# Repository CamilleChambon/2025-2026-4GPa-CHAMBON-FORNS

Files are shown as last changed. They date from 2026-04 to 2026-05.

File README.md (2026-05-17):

# 2025-2026-4GPa-CHAMBON-FORNS-GIRAUD
## SOMMAIRE
*** 
  - [I. Description Projet Graphite](#description-projet-graphite)
  - [II. Livrables](#livrables)
  - [III. Matériel nécessaire](#matériel-nécessaire)
  - [IV. Electronique Analogique sous LTSpice](#electronique-analogique-sous-ltspice)
  - [V. Création du PCB sous KiCad](#creation-du-pcb-sous-kicad)
  - [VI. Réalisation du shield](#réalisation-du-shield)
  - [VII. Code Arduino](#code-arduino)
  - [VIII. Application Android](#application-android)
  - [IX. Banc de test](#banc-de-test)
  - [X. Datasheet](#datasheet)
  - [XI. Conclusion](#conclusion)

*** 

## Description Projet Graphite

&nbsp;&nbsp;&nbsp;&nbsp;&nbsp;&nbsp; Dans le cadre du cours "Du capteur au banc de test" de 4e année de Génie Physique, nous avons développé un capteur de contrainte basé sur une technologie low-tech. Comme présenté en introduction de la datasheet (cf. section X), le capteur Graphite est un capteur de contrainte résistif, composant passif qui fonctionne en mesurant les variations de résistance d'une fine couche de graphite appliquée au crayon à papier sur une surface papier. Lorsque ce dernier est déformé en tension ou en compression, la répartition des particules de graphite est modifiée, entraînant respectivement une hausse ou une baisse de sa résistance. Par la mesure de ces variations de résistance, il est possible de remonter à la variation de résistance. 

&nbsp;&nbsp;&nbsp;&nbsp;&nbsp;&nbsp; Le projet a consisté à développer un système complet autour de ce capteur : modélisation d'électronique analogique grâce au logiciel LTSpice, création d’un circuit imprimé (PCB) via Kicad, programmation avec Arduino, création d'une application mobile avec MIT App Inventor, et communication sans fil par Bluetooth, entre le téléphone et le système. Un banc de test a été spécialement réalisé en impression 3D pour évaluer les performances du capteur, grâce à des pièces circulaires de différents rayons de courbure. En ce qui concerne les codes, ayant rencontré des problèmes pour faire fonctionner l'écran OLED, nous avons rédigé deux codes distincts, l'un avec l'écran, l'autre sans.

## Livrables

  - Shield PCB compatible avec Arduino UNO, intégrant un capteur graphite, un amplificateur transimpédance, un module Bluetooth, un écran OLED, un flex sensor, un potentiomètre digital et un encodeur rotatoire.
  - Code Arduino assurant la lecture du capteur, l’affichage des données, la communication Bluetooth et l’interaction avec les composants.
  - Application Android réalisée sous MIT App Inventor pour visualiser les mesures transmises par Bluetooth.
  - Graphes des variations relatives de résistance du capteur graphite - en tension et en compression - et du flex sensor pour montrer les résultats obtenus sur le banc de test.
  - Datasheet du capteur de graphite, présentant ses principales caractéristiques, les résultats expérimentaux et un exemple de circuit d'utilisation courant.

## Matériel nécessaire

  - 1 carte Arduino Uno
  - 2 Résistances de 100kΩ
  - 1 Résistance de 1kΩ
  - 1 Potentiomètre digital MCP-41050
  - 2 Condensateurs 100nF
  - 1 Condensateur 1µF
  - 1 Amplificateur LTC1050
  - 1 Écran OLED01
  - 1 Module Bluetooth HC-05
  - 1 Encodeur rotatoire 

## Electronique Analogique sous LTSpice

Notre capteur graphite présente une résistance de l’ordre du gigaOhm, ce qui génère un courant de quelques pico à nano Ampères sous une tension de 5 V. Pour rendre ce signal exploitable par l’ADC d’une Arduino UNO, nous avons conçu un amplificateur transimpédance autour de l’AOP LTC1050. Après avoir modélisé le capteur et le montage sous LTspice pour déterminer la meilleure valeur de la résistance de rétroaction, nous avons ajouté trois étages de filtrage, fondés sur des filtres passe-bas, afin d'améliorer la qualité du signal en éliminant les hautes fréquences parasites, en atténuant le bruit secteur à 50 Hz et en supprimant les interférences liées à l’ADC.  

Ce circuit convertit ainsi le faible courant issu du capteur en une tension propre, directement lisible et traitable par la carte Arduino.

<p align="center">
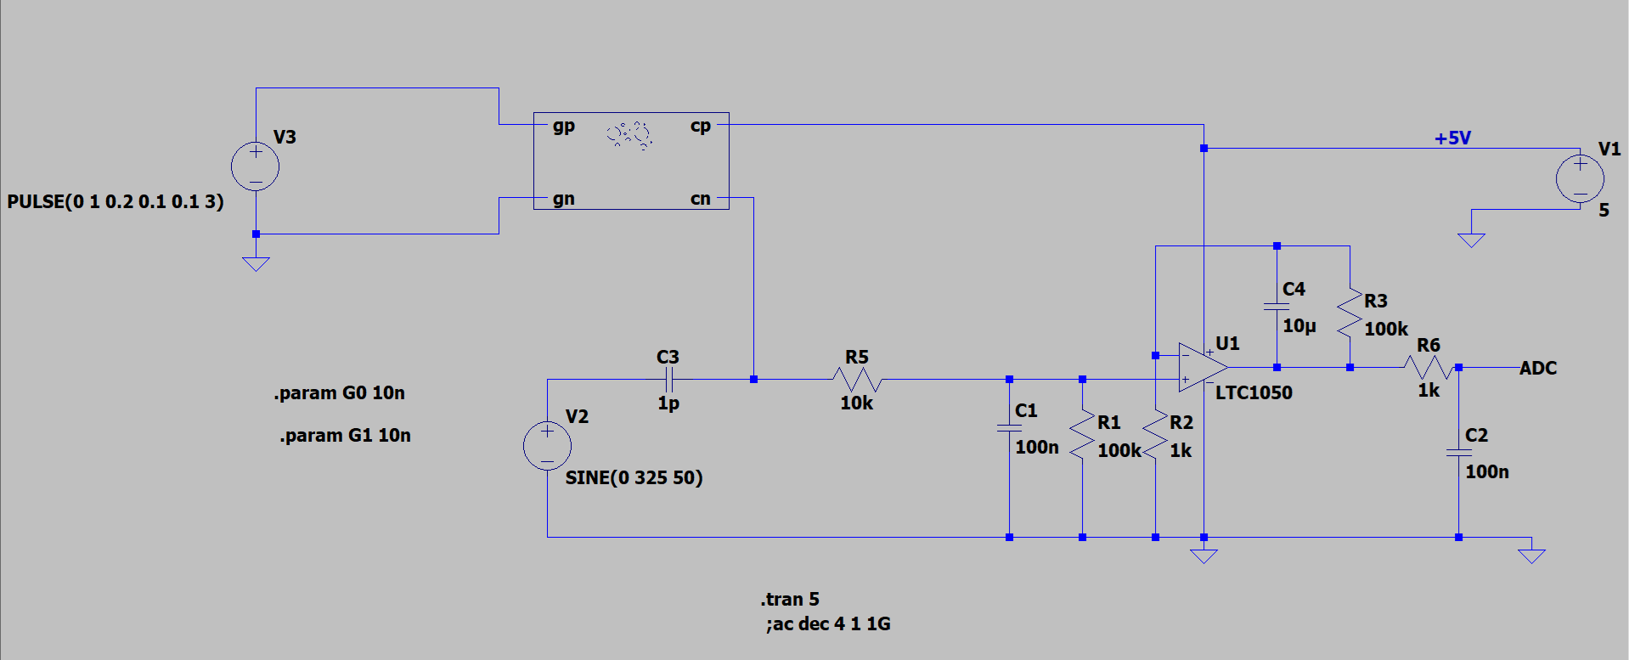
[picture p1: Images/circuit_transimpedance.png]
Figure 1 - Circuit amplificateur

<br>
<i>Circuit amplificateur transimpédance</i>
</p>

## Création du PCB sous KiCad

Lors de la phase de conception du shield, nous avons d’abord repris le gabarit d’une carte Arduino UNO dans KiCad (version 8.0) puis nous avons créé sur le même logiciel les symboles et empreintes manquants pour l'ensemble des composants que nous utiliserions, en respectant leurs dimensions et l’écartement des broches. Voici le schéma électrique de l'ensemble de notre montage :

<p align="center">
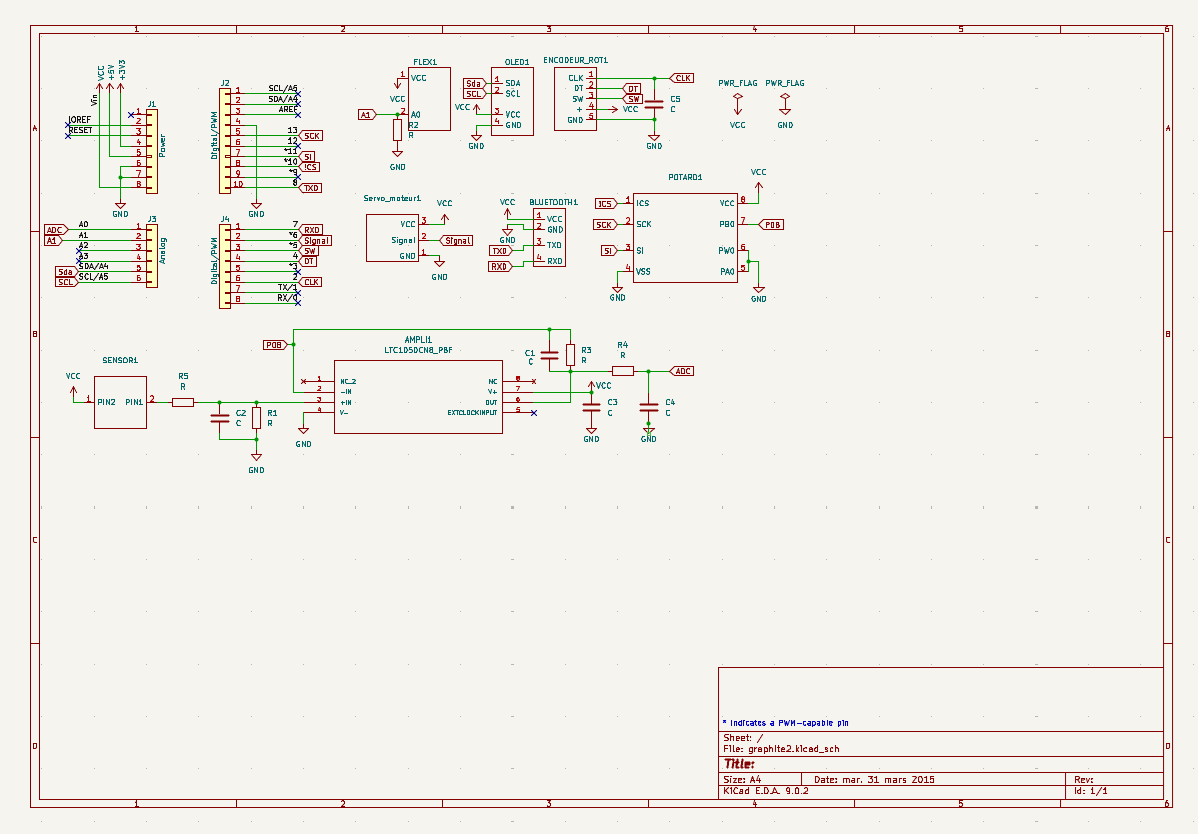
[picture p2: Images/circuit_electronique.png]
Figure 1 - Circuit électronique

<br>
<i>Circuit électronique</i>
</p>

Une fois notre bibliothèque faite, nous avons assemblé le schéma électrique complet : chaque composant est relié selon le fonctionnement prévu. Sur la vue PCB, nous avons disposé les empreintes, effectué le routage des pistes, le tout afin d'optimiser l'espace disponible et de limiter le nombre de vias réalisés. Les résistances ont été positionnées verticalement sur le PCB. Enfin, nous avons ajouté un plan de masse pour relier certaines pistes au GND.
Voici notre PCB :

<p align="center">
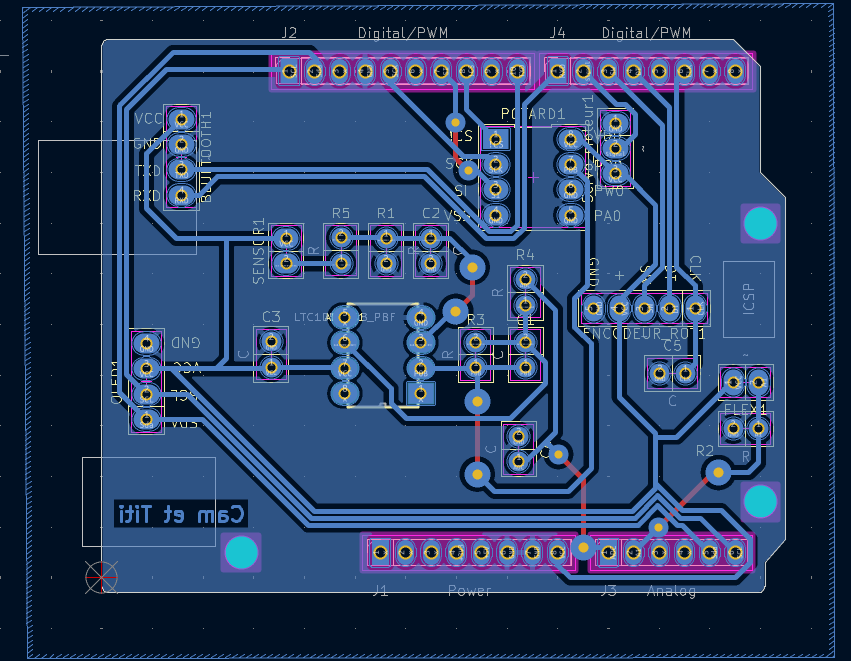
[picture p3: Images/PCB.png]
Figure 1 - PCB Final

<br>
<i>PCB</i>
</p>

Le résultat est un circuit imprimé prêt à être fabriqué et à recevoir chaque composant sur le shield Arduino UNO.

## Réalisation du Shield

Nous avons commencé par l’édition du masque de gravure de notre circuit imprimé (PCB) à l’aide du logiciel KiCad. Ensuite, nous avons procédé à l’insolation UV d’une plaquette recouverte d’une fine couche de cuivre et de résine photosensible. La plaquette a été immergée dans un révélateur chimique, ce qui permet d’éliminer la résine non exposée aux UV. Par la suite, on plonge la plaquette dans du perchlorure de fer pour graver les pistes du circuit en dissolvant le cuivre non protégé. Enfin, il faut un nettoyage à l’acétone pour retirer les résidus de résine restant sur la plaquette. A la fin de ce travail, nous avions notre circuit imprimé avec toutes les pistes tracées.
Une fois le PCB réalisé, nous n'avions plus qu'à le percer et y souder tous nos composants. Voici notre PCB final :

<p align="center">
<img src="Images/shield.jpg"Figure 4 - Notre PCB">
<br>
<i>Notre PCB</i>
</p>

## Code Arduino 

Ce projet a été piloté par un [programme Arduino](Code%20Arduino). Pour utiliser les fonctions spéciales à tous les composants, nous avons installé les librairies Adafruit_SSD1306.h et Adfruit_GFX.h, SPI.h, Servo.h et SoftwareSerial.h.

Nous avons joint sur ce github deux codes distincts, avec des caractéristiques communes cependant.

Le code intitulé "code_final" est un code qui utilise les deux capteurs (flex et graphite), le servo-moteur, le module bluetooth et le potentiomètre. Il réalise deux étapes : une calibration, pour ramener à 2,5 V, la tension lue aux bornes du capteur graphite sans déformation, puis un cycle de mesure. Ces étapes sont lancées depuis les boutons de l'application Android (cf. infra). Lors d'un cycle de mesure, réalisé sur notre banc de test, le moteur avance d'un certain nombre de pas, puis l'on réalise une série de mesures dont on fait la moyenne pour obtenir une valeur stable, que l'on affiche ensuite sur l'application. Puis, le moteur avance de nouveau, et ainsi de suite. Plusieurs paramètres peuvent être réglés sur l'application Android :
- l'angle est la plage angulaire totale couverte par le servo-moteur;
- le nombre de mesures est le nombre de mesures sucessives que l'on réalise pour calculer une moyenne *sur une seule valeur de déformation* ;
- le nombre de pas correspond au nombre de points que l'on va afficher au final, c'est-à-dire, le nombre de mesures effectives réalisées.

Le code appelé "main" repose sur le même principe, bien qu'il ne présente pas d'étape de calibration. Cependant, il présente par ailleurs des menus affichés sur l'écran OLED permettant de régler les paramètres précisés supra, et utilise l'encodeur rotatoire comme moyen de se déplacer dans ces menus. Il est associé à un programme Python récupérant les données pour les afficher dans des graphiques.

## Application Android

Nous avons conçu une application Android en utilisant la plateforme MIT App Inventor. Cette application permet de recevoir les données de la carte Arduino via une connexion Bluetooth en utilisant le module HC-05 qui se trouve sur notre PCB. Après la connexion bluetooth, l'application nous donne en temps réel la valeur de la résistance du capteur graphite et trace sa courbe en fonction du temps sur un graphique. Vous la trouverez [Application MIT_App_Inventor](https://github.com/CamilleChambon/2025-2026-4GPa-CHAMBON-FORNS/tree/main/Application%20MIT_App_Inventor).

## Banc de test

Après avoir réalisé le montage électrique complet, ainsi que les parties softwares adéquates, il était nécessaire de tester notre capteur ainsi que le capteur commercial pour pouvoir les comparer. Pour cela, nous avons utilisé le banc de test ci-dessous, constitué de pièces circulaires de différents rayons de courbure (2 cm, 3 cm, 4 cm, 5 cm).

<p align="center">
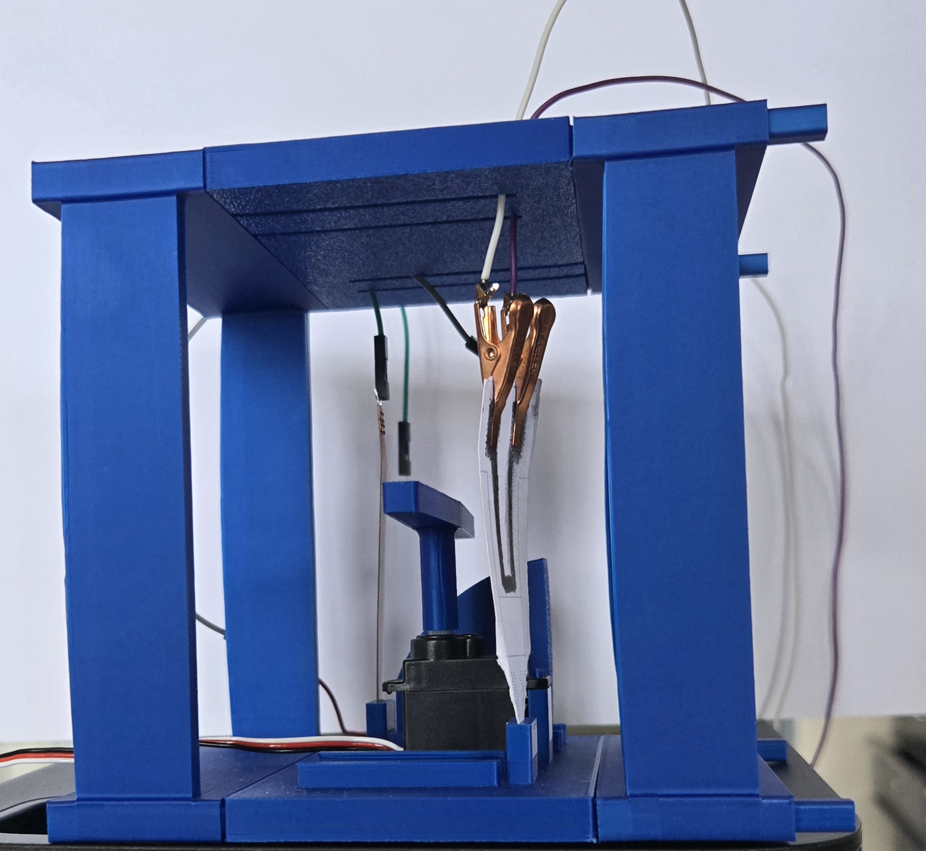
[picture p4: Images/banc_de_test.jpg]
Figure 6 - Banc de Test

<br>
<i>Banc de test utilisé</i>
</p>

Pour toutes les mesures, la résistance du potentiomètre digital était déterminée par la fonction de calibration. En ce qui concerne le capteur graphite, nous déposions du graphite issu de crayons HB, 3B et B. Nous n'avons pas réussi à obtenir des valeurs convenables avec des crayons plus durs.

Le principe du test est de poser le capteur et le flex sensor et de le tordre petit à petit à l'aide des pales du moteur qui tournent. Cela permet d'obtenir les valeurs de résistance en fonction de la déformation appliquée.

Pour nos calculs, les valeurs qui nous intéressent sont la variation relative de résitance (fraction)
en fonction de la déformation (fraction). 

Voici les courbes caractéristiques du capteur graphite, en tension et en compression : 

<p align="center">
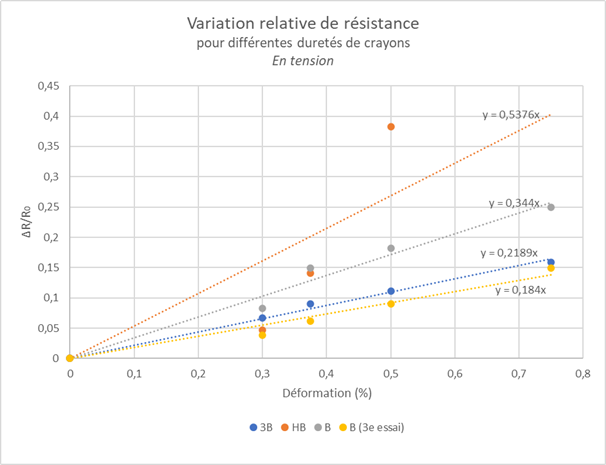
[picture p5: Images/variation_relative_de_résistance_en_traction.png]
Figure 7 - Tension

<br>
</p>

<p align="center">
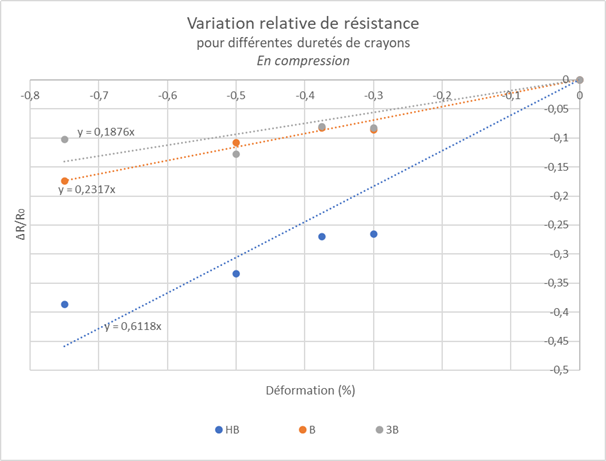
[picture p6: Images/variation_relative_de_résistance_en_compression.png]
Figure 8 - Compression

<br>
</p>

Et ci-dessous la caractéristique du flex sensor en tension : 

<p align="center">
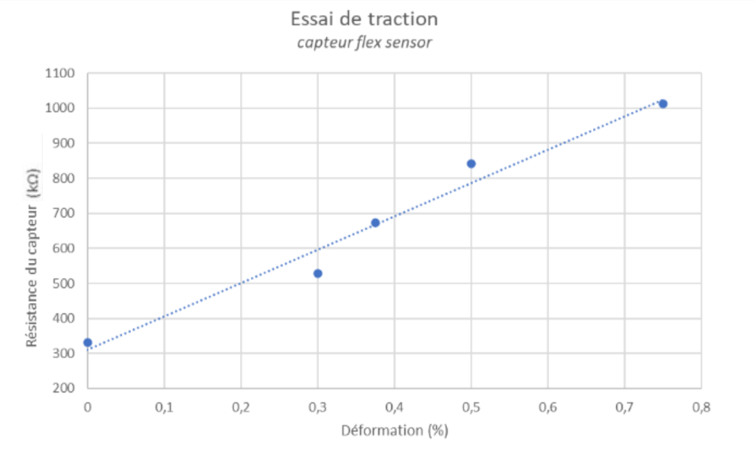
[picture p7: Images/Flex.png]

<br>
</p>

Nous remarquons que la résistance évolue lorsque le capteur graphite est soumis à une déformation. En tension, la résistance augmente, tandis qu'en compression, elle diminue. Ce phénomène s'explique par le rapprochement des atomes lors de la compression, facilitant ainsi le passage du courant. Lors de la tension, les atomes s'éloignent, le courant a alors plus de mal pour passer. Les résultats montrent aussi que le type de crayon utilisé influence les valeurs de résistance mesurées. 

La capacité de déformation en compression du capteur graphite n'est pas très fiable selon nos résulats. Le modèle linéaire attendu s'éloigne de la caractéristique sur les grosses déformations. Ceci peut être en partie dû au frottement du graphite sur le banc de test, qui peut perturber l'agencement des atomes et ainsi les mesures réalisées. 

Ces résultats expérimentaux permettent de conclure que le capteur commercial est globalement plus sensible à la déformation que les capteurs en graphite, même si cette dernière est acceptable. De plus, il possède une certaine robustesse contrairement aux capteurs en papier : ceux-ci sont fragiles et n'importe quel contact peut altérer le gtaphite déposé. Le nombre d'utilisation est aussi limité, entre 3 et 5 séries de tests pour la plupart. Au-delà, les variations de résistance étaient très aléatoires et parfois inexistantes. Il était également nécessaire de déposer une grande quantité de graphite sur le papier pour pouvoir mesurer une résistance, notamment avec des crayons gras. 

## Datasheet

La datasheet de notre capteur est disponible [ici](Datasheet).

## Conclusion

Grâce à la série d'étapes amenant aux tests réalisés sur les deux capteurs, nous pouvons répondre à la question posée initialement, à savoir : le capteur graphite est industrialisable ou non ? 

Comme mentionné dans la partie [IX. Banc de test](#banc-de-test), les résultats montrent que le capteur commercial possède plusieurs avantages par rapport au capteur graphène. Il est plus fiable, plus durable et moins contraignant. Ces éléments peuvent rendre une commercialisation à grande échelle plus complexe dans l’état actuel du prototype.

Néanmoins, le capteur graphite demeure une option particulièrement pertinente dans certains contextes d’usage. Sa sensibilité s’est révélée plus qu’acceptable, et il est capable d’effectuer des mesures en compression, ce qui confirme la viabilité du concept. Pour des applications ponctuelles, rapides ou à usage unique, il constitue une alternative crédible et efficace.

Par ailleurs, ce capteur présente des atouts importants liés à sa philosophie de conception : son faible coût, sa simplicité de fabrication et son caractère low-tech le rendent particulièrement accessible. Utilisant des matériaux simples et peu transformés, il s’inscrit également dans une démarche plus sobre et écologique que certaines solutions commerciales plus complexes. Il conserve donc un réel intérêt.

Des pistes d’amélioration restent envisageables, notamment pour renforcer ses performances en compression (par exemple via une protection du graphite à l’aide d’un gel ou d’un matériau souple adapté) tout en conservant l’accessibilité et la simplicité qui font sa force. L’enjeu serait ainsi d’améliorer sa robustesse sans compromettre son aspect économique et durable.

Ce projet fut particulièrement enrichissant, car il nous a permis de concevoir à la fois les parties software et hardware d’un capteur, puis de le caractériser expérimentalement et d’élaborer une datasheet. Les différentes étapes du projet nous ont permis d’acquérir de nouvelles connaissances et compétences, que nous serons probablement amenés à mobiliser dans notre future carrière d’ingénieur physicien. Nous remercions nos professeurs pour leur accompagnement et pour nous avoir proposé ce projet tout au long du semestre.

Vous pouvez nous contacter si vous avez la moindre question :
- Timothy FORNS : forns@insa-toulouse.fr
- Camille CHAMBON : chambo@insa-toulouse.fr
- Faustine GIRAUD : girau@insa-toulouse.fr

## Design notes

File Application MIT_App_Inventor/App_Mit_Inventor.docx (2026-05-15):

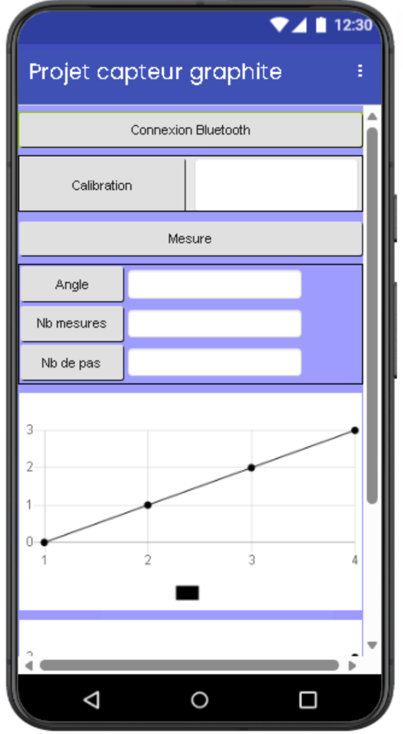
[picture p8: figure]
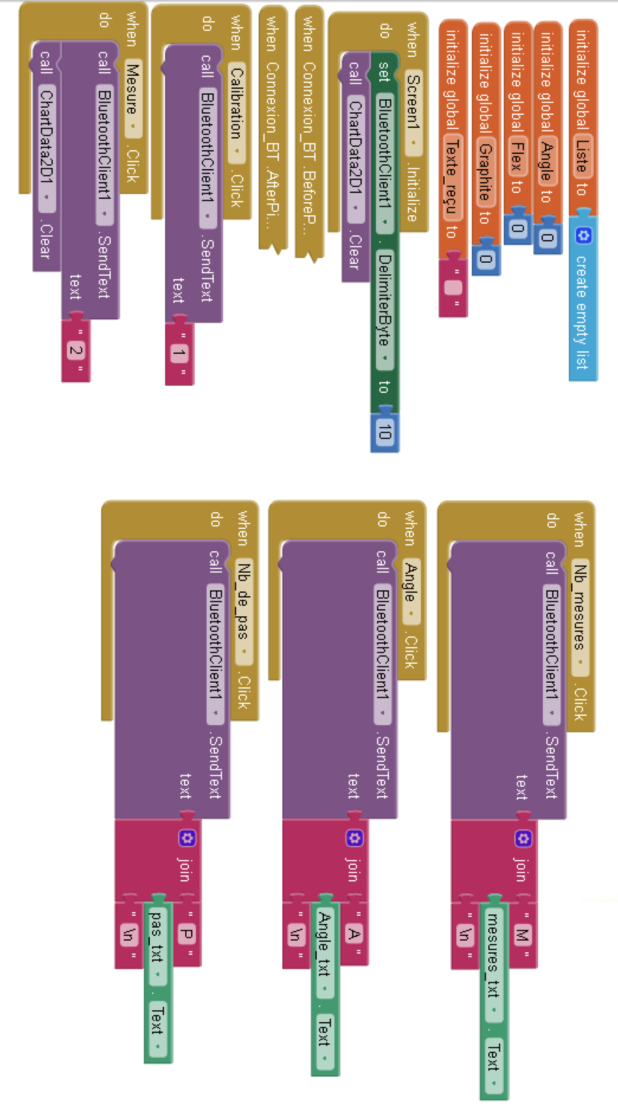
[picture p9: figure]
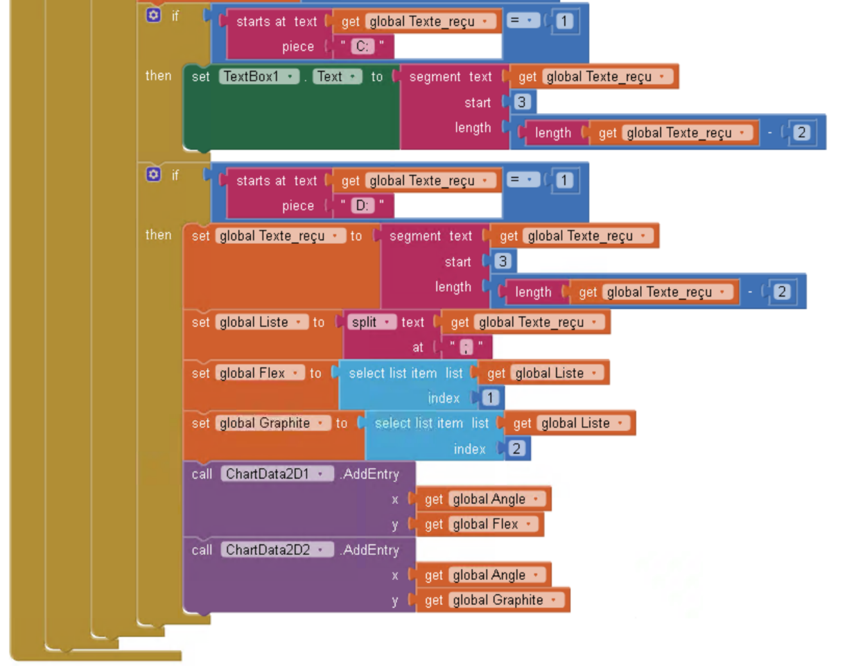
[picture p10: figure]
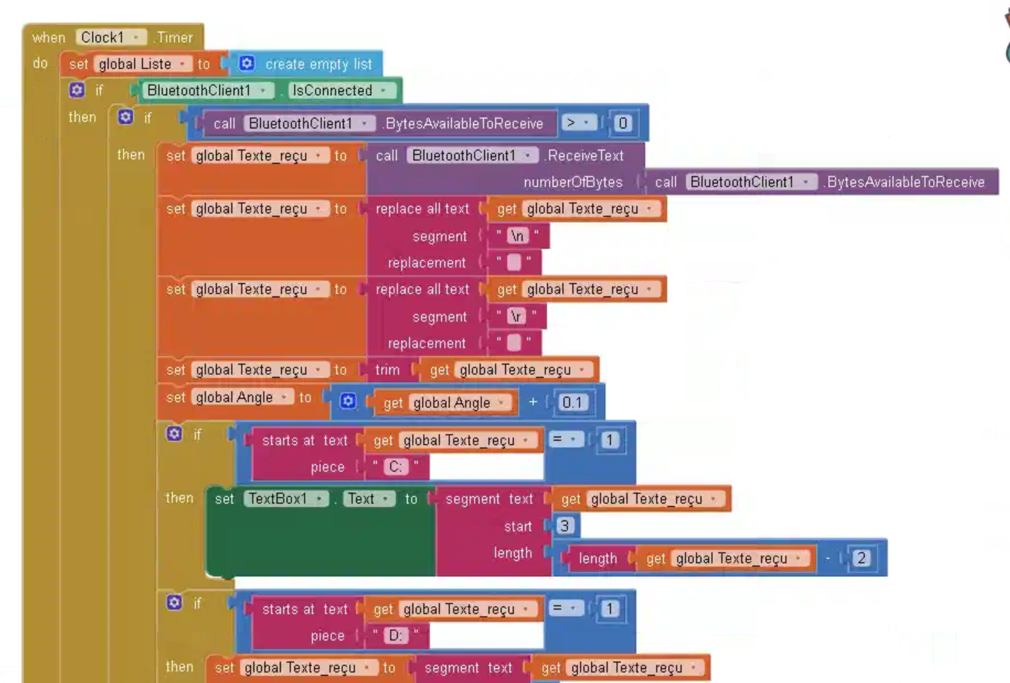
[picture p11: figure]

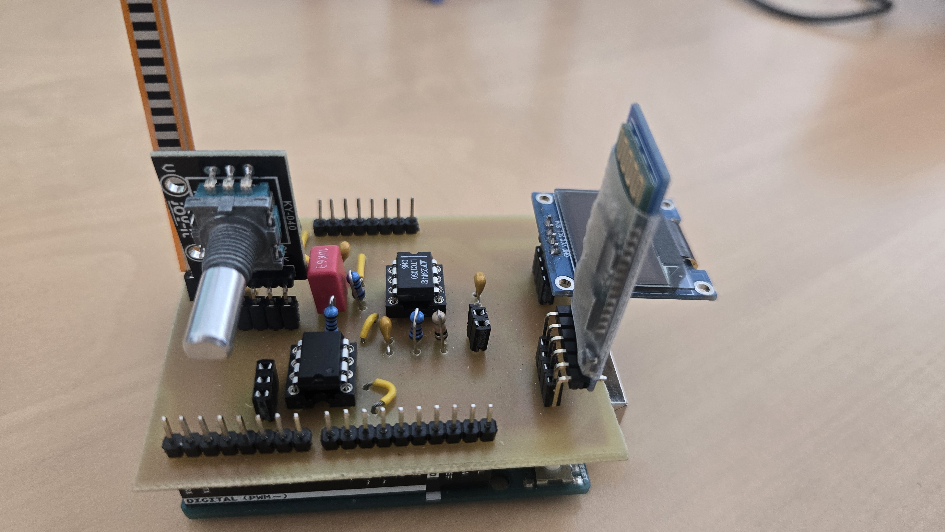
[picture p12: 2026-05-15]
Images/shield.jpg

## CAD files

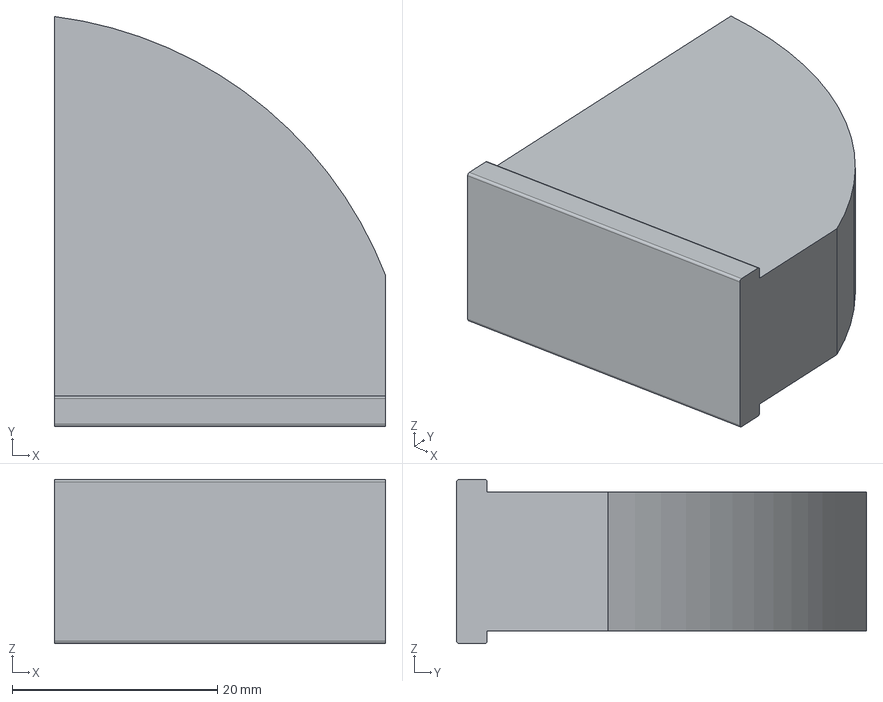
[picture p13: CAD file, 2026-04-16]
Banc_de_test/pièce_guidage_40mm-Body.step
32.3 x 40.0 x 16.0 mm

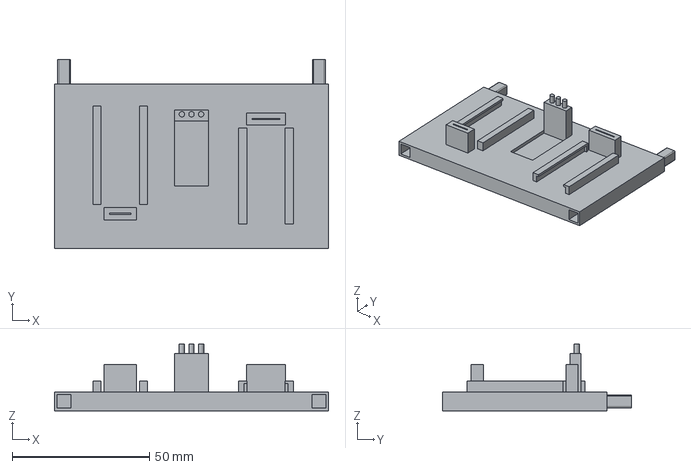
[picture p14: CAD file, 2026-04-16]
Banc_de_test/bas-Corps.step
100.0 x 69.0 x 24.4 mm

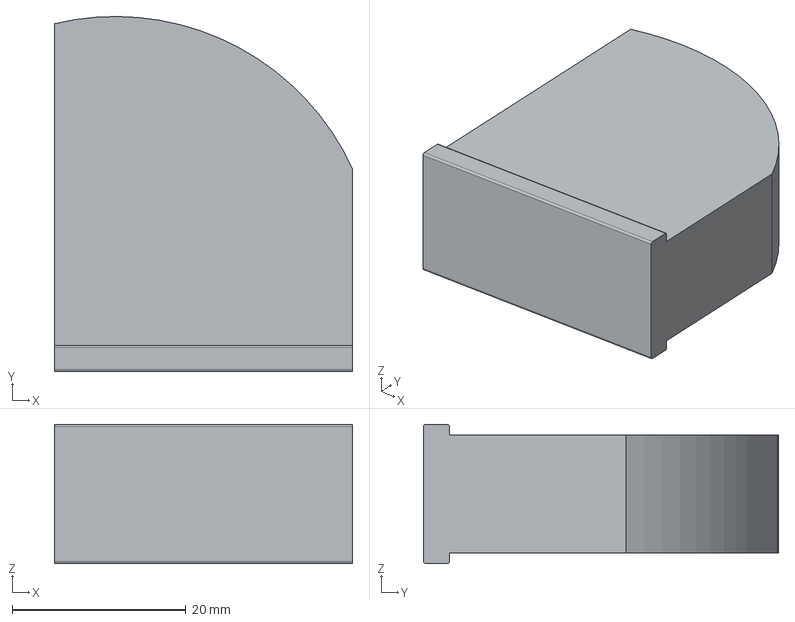
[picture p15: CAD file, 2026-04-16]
Banc_de_test/pièce_guidage_30mm-Body.step
34.3 x 40.8 x 16.0 mm

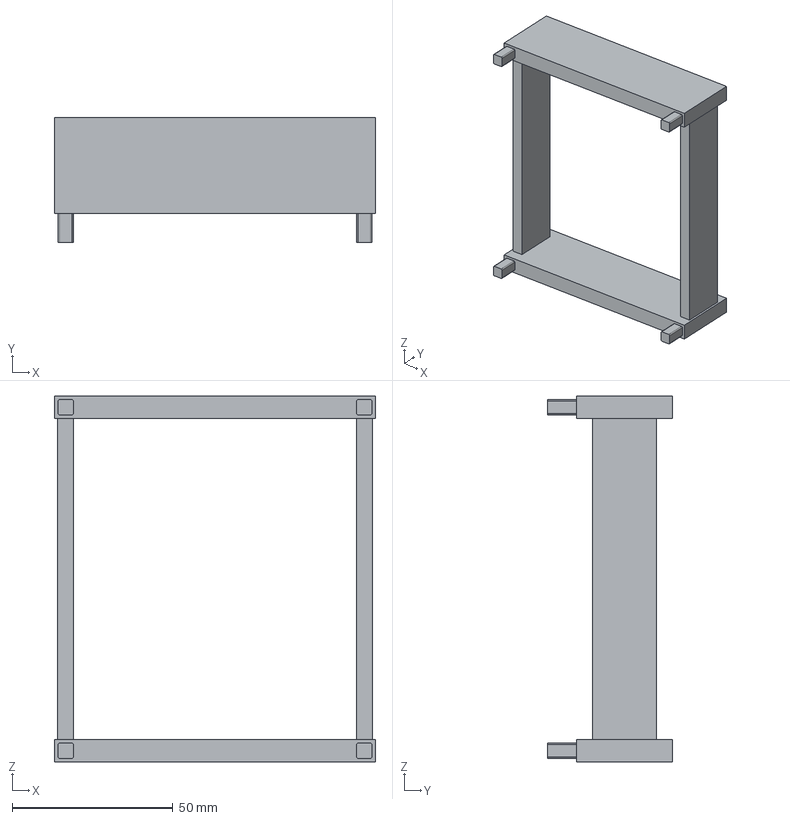
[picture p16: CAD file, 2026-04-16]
Banc_de_test/adaptateur boite-Body.step
100.0 x 39.0 x 114.0 mm

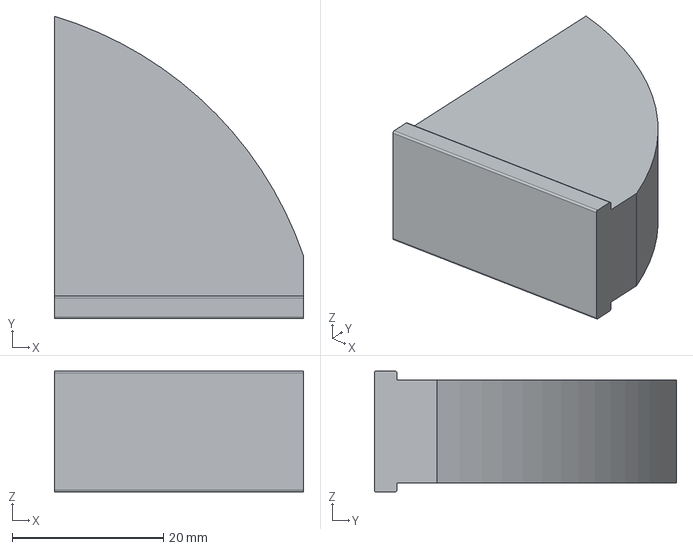
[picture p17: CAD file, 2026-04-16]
Banc_de_test/pièce_guidage_50mm-Body.step
32.9 x 40.0 x 16.0 mm

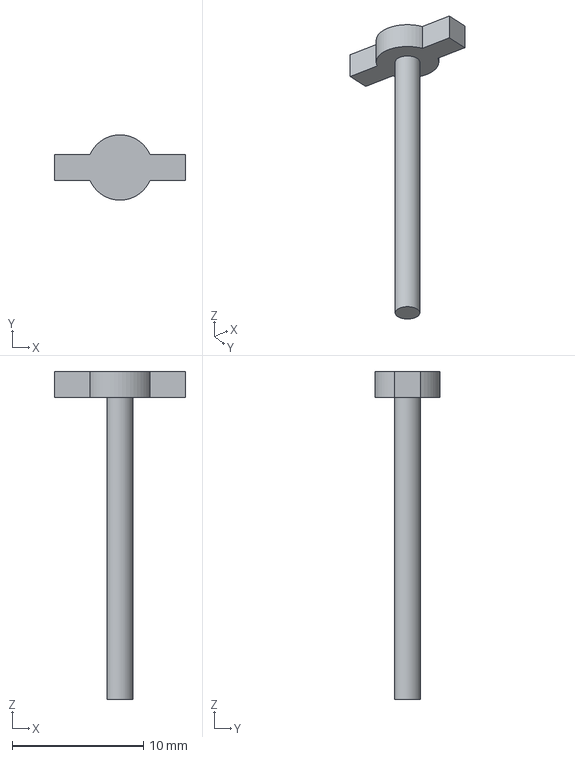
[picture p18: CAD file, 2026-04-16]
Banc_de_test/fixe_bras-Body.step
10.0 x 4.97 x 25.0 mm

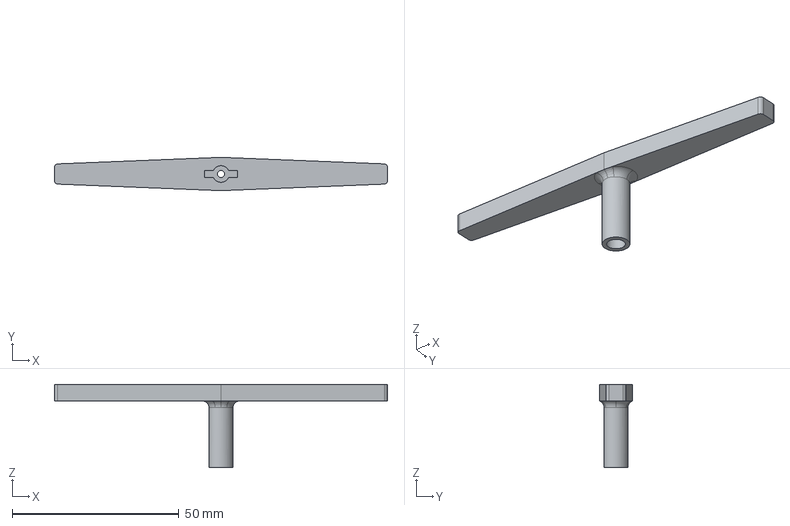
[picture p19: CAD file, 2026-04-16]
Banc_de_test/bras-Body.step
100.0 x 10.0 x 25.0 mm

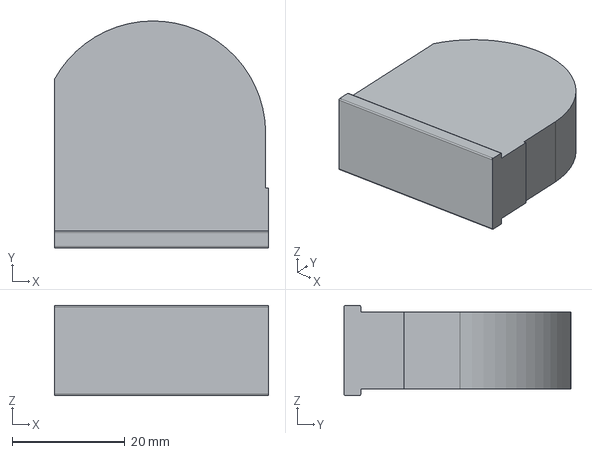
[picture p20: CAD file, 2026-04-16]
Banc_de_test/pièce_guidage_20mm-Body.step
38.0 x 40.3 x 16.0 mm

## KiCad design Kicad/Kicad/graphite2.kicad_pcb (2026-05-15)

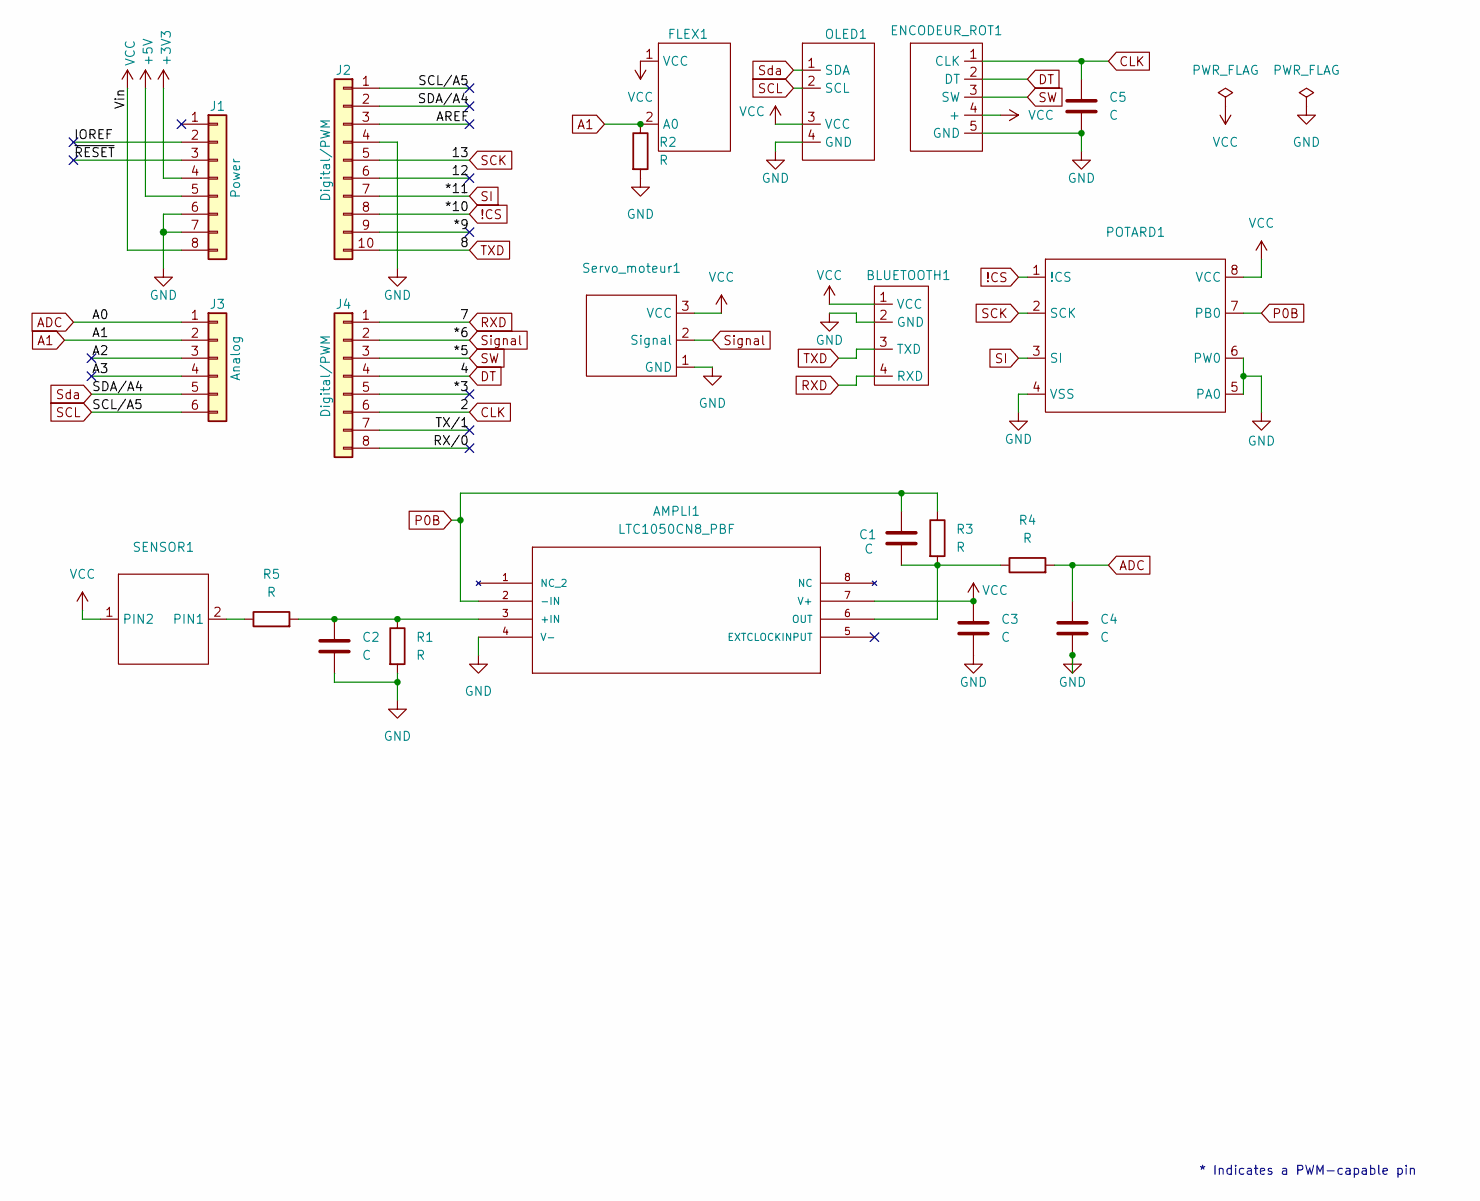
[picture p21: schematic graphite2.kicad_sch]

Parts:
AMPLI1: LTC1050CN8_PBF; PDIP-8_N; MANUFACTURER_PART_NUMBER ltc1050cn8
BLUETOOTH1: Bluetooth_HC05
C1, C2, C3, C4, C5: C
ENCODEUR_ROT1: ENCODEUR_empreinte
FLEX1: FLEX
J1: Power; PinSocket_1x08_P2.54mm_Vertical
J2: Digital/PWM; PinSocket_1x10_P2.54mm_Vertical
J3: Analog; PinSocket_1x06_P2.54mm_Vertical
J4: Digital/PWM; PinSocket_1x08_P2.54mm_Vertical
OLED1: OLED_empreinte
POTARD1: POTENTIO MCP
R1, R2, R3, R4, R5: R
SENSOR1: SENSOR
Servo_moteur1: SERVOMOTEUR

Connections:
!CS: J2.8, POTARD1.1 (!CS)
+3V3: J1.4
+5V: J1.5
/12: J2.6
/*3: J4.5
/*9: J2.9
/A2: J3.3
/A3: J3.4
/AREF: J2.3
/IOREF: J1.2
/RX/0: J4.8
/TX/1: J4.7
/~RESET: J1.3
A1: FLEX1.2 (A0), J3.2, R2.1
ADC: C4.1, J3.1, R4.2
CLK: C5.1, ENCODEUR_ROT1.1 (CLK), J4.6
DT: ENCODEUR_ROT1.2 (DT), J4.4
GND: AMPLI1.4 (V-), BLUETOOTH1.2 (GND), C2.2, C3.2, C4.2, C5.2, ENCODEUR_ROT1.5 (GND), J1.6, J1.7, J2.4, OLED1.4 (GND), POTARD1.4 (VSS), POTARD1.5 (PA0), POTARD1.6 (PW0), R1.2, R2.2, Servo_moteur1.1 (GND)
unnamed: AMPLI1.3 (+IN), C2.1, R1.1, R5.2
unnamed: AMPLI1.6 (OUT), C1.2, R3.2, R4.1
unnamed: R5.1, SENSOR1.2 (PIN1)
P0B: AMPLI1.2 (-IN), C1.1, POTARD1.7 (PB0), R3.1
RXD: BLUETOOTH1.4 (RXD), J4.1
SCK: J2.5, POTARD1.2 (SCK)
SCL: J2.1, J3.6, OLED1.2 (SCL)
SI: J2.7, POTARD1.3 (SI)
SW: ENCODEUR_ROT1.3 (SW), J4.3
Sda: J2.2, J3.5, OLED1.1 (SDA)
Signal: J4.2, Servo_moteur1.2 (Signal)
TXD: BLUETOOTH1.3 (TXD), J2.10
VCC: AMPLI1.7 (V+), BLUETOOTH1.1 (VCC), C3.1, ENCODEUR_ROT1.4 (+), FLEX1.1 (VCC), J1.8, OLED1.3 (VCC), POTARD1.8 (VCC), SENSOR1.1 (PIN2), Servo_moteur1.3 (VCC)

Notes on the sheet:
* Indicates a PWM-capable pin

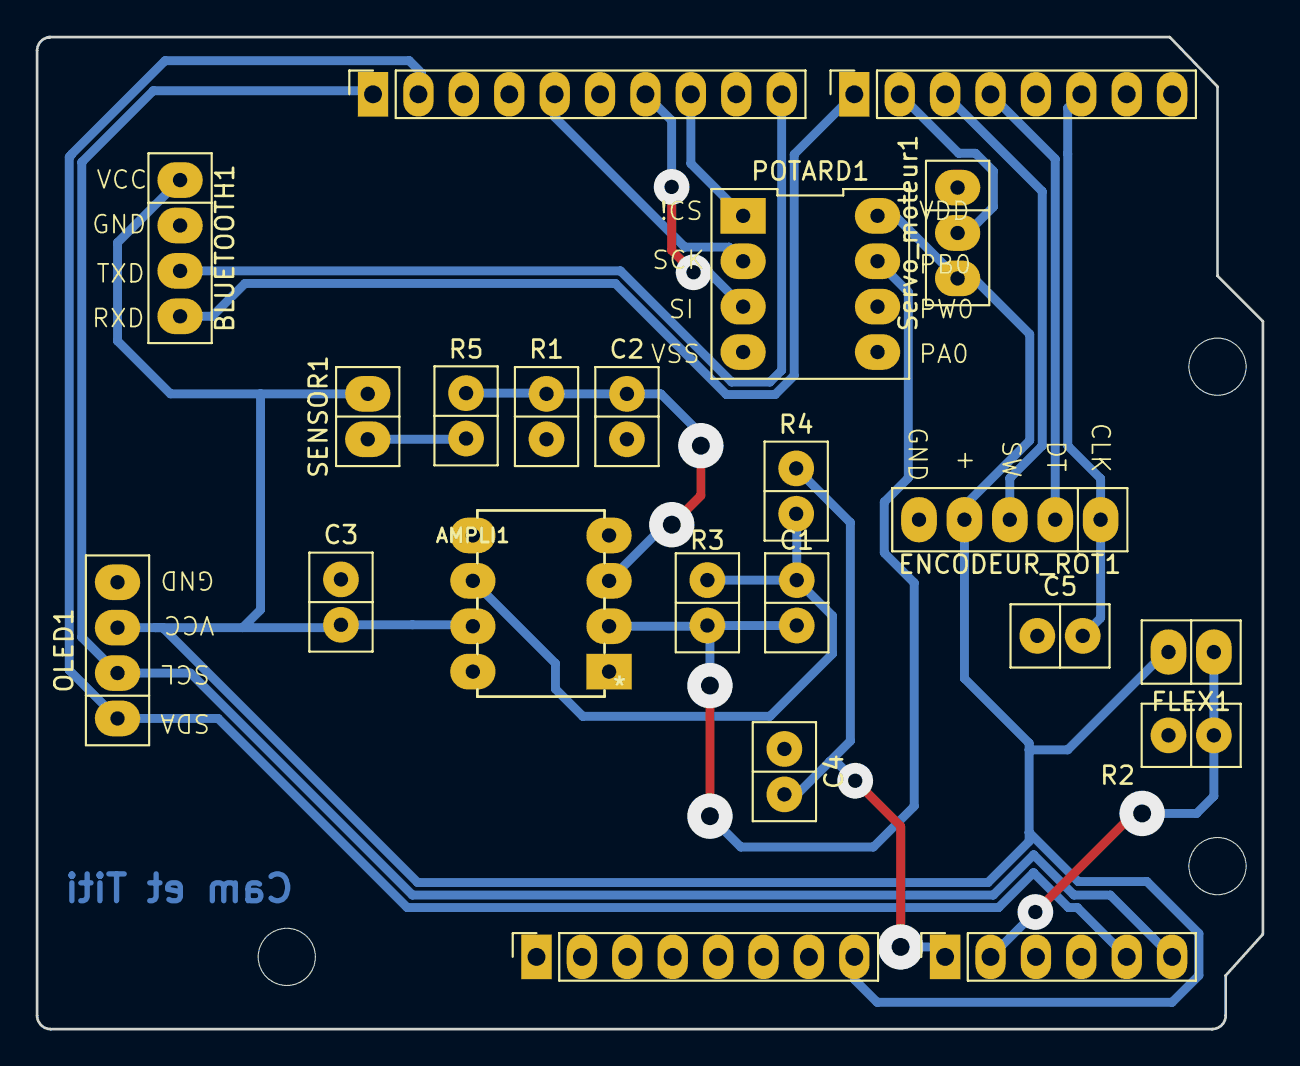
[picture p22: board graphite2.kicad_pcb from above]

Board: 2 copper layers, 68.6 x 55.5 mm, 25 parts (0 on the bottom side), 19 nets.

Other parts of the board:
MH2, MH3, MH4: MountingHole_3.2mm

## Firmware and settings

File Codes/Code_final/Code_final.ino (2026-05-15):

#include <Wire.h>
#include <Adafruit_SSD1306.h>
#include <Adafruit_GFX.h>
#include <Servo.h>
#include <SoftwareSerial.h>                 // Librairie Bluetooth
#include <SPI.h>                            // Librairie Potentiometre 
#include <stdlib.h>

//-------------------------------------------------//
//                                                 //
//                   DEFINITIONS                   //
//                                                 //
//-------------------------------------------------//

const int VCC = 5;

// --- RESISTANCES CIRCUIT ---
const float R1 = 100000 ;
float R_POTARD ;
const float R3 = 100000;
const float R5 = 10000 ;


// --- POTENTIOMETRE ---
#define MCP_NOP 0b00000000 //Commandes pour potentiomètre (non)
#define MCP_WRITE 0b00010001 //Commandes pour potentiomètre (écriture)
#define MCP_SHTDWN 0b00100001 //Commandes pour potentiomètre (shutdown)
const int ssMCPin = 10; // Define the slave select for the digital pot

// --- Bluetooth ---
#define txPin 7
#define rxPin 8
char serialRX[20];// variable de reception de donnée via RX
char serialTX; // variable de transmission de données via TX
const int speed_serial = 9600;      // communication Bluetooth 
SoftwareSerial mySerial (rxPin, txPin);

// --- Servo ---
Servo myservo;
const int SERVO_PIN = 6;

// --- Capteurs ---
const int FLEX_PIN      = A1;
const int GRAPHITE_PIN  = A0;
const float R_SHUNT     = 10000.0; // Flex 10kΩ
const float GAIN        = 1.0;     // Graphite amplifié

// --- Paramètres ---
int angleMax = 90;
int numSteps = 90;
int numMeasures = 1;
int parameterIndex = 0;
bool readyToStart = true;

//-------------------------------------------------//
//                                                 //
//                   CALIBRATION                   //
//                                                 //
//-------------------------------------------------//

// Fonction écriture d'une donnée dans le MCP IC connecté au ssPin
void SPIWrite(uint8_t cmd, uint8_t data, uint8_t ssPin) 
{
  SPI.beginTransaction(SPISettings(14000000, MSBFIRST, SPI_MODE0)); //https://www.arduino.cc/en/Reference/SPISettings
  
  digitalWrite(ssPin, LOW); // SS pin low to select chip
  
  SPI.transfer(cmd);        // Send command code
  SPI.transfer(data);       // Send associated value
  
  digitalWrite(ssPin, HIGH);// SS pin high to de-select chip
  SPI.endTransaction();
}

int Calibration() {
  int Pos_pot = 255; // valeur à entrer dans le potentiomètre pour faire varier sa résistance
  float Vmoy = 2.5; // Valeur de tension vers laquelle on veut tendre
  float Vgraphite; // tension lue en sortie de l'AO
  
  // Recherche type minimum entre 2,5 et Vgraphite
  float Min = 100; // valeur inaccessible
  float Pos_min; // pour retenir la consigne à donner au potentiomètre
  
  do {
    SPIWrite(MCP_WRITE, (uint8_t)Pos_pot, ssMCPin);
    
    delay(150);
    
    int rawADC = analogRead(GRAPHITE_PIN); // Première lecture pour "réveiller" l'ADC
    rawADC = analogRead(GRAPHITE_PIN);    // Deuxième lecture pour la précision
    
    Vgraphite = rawADC * (5.0 / 1023.0);
    
    Serial.print("Pot: "); Serial.print(Pos_pot);
    Serial.print(" -> V: "); Serial.println(Vgraphite);

    if (Pos_pot <= 1) break; // Sécurité pour éviter l'underflow
    if (abs(Vmoy - Vgraphite) < Min) {
      Min = abs(Vmoy - Vgraphite);
      Pos_min = Pos_pot;
    }
    Pos_pot -= 1;
  } while (Pos_pot > 0 && Pos_pot <= 255);

  SPIWrite(MCP_WRITE, (uint8_t)Pos_min, ssMCPin);

  R_POTARD = (Pos_min*10000.0)/255.0;
  Serial.print("Commande min : ") ; Serial.println(Pos_min);
  Serial.print("Résistance R2 correspondante : ") ; Serial.println(R_POTARD);
  return (R_POTARD);
}

//-------------------------------------------------//
//                                                 //
//                  CYCLE MESURE                   //
//                                                 //
//-------------------------------------------------//

// --- Cycle servo + mesure ---
void runCycle(){
  Serial.println("START"); // signal pour Python

  float angleStep = float(angleMax)/float(numSteps);
  int stepDelay = 1000; // ms

  for(int i=0; i<=numSteps; i++){
    int angle = round(i*angleStep);
    myservo.write(angle);
    delay(stepDelay);

    float sumFlex = 0;
    float sumGraphite = 0;

    for(int m=0; m<numMeasures; m++){
//      if(sensorMode == FLEX_ONLY || sensorMode == BOTH){
        int adcFlex = analogRead(FLEX_PIN);
        float Rflex = R_SHUNT * (1023.0/float(adcFlex) - 1.0);
        sumFlex += Rflex;
//      }
//      if(sensorMode == GRAPHITE_ONLY || sensorMode == BOTH){
        int adcGraphite = analogRead(GRAPHITE_PIN);
        float Vgraphite = adcGraphite * (5.0 / 1024.0);
        float Rgraphite = (1+(R3/R_POTARD))*R1*(VCC/Vgraphite)-R1-R5 ;
        sumGraphite += Rgraphite;
//      }
    }

    float avgFlex = /*(sensorMode == FLEX_ONLY || sensorMode == BOTH) ?*/ sumFlex/float(numMeasures) /*: 0*/;
    float avgGraphite = /*(sensorMode == GRAPHITE_ONLY || sensorMode == BOTH) ?*/ sumGraphite/float(numMeasures) /*: 0*/;

    String Data = String(avgFlex) + ";" + String(avgGraphite) ;
    mySerial.println("D: " + Data);

    Serial.print("Flex --> "); Serial.println(avgFlex); 
    Serial.print("Graph --> "); Serial.println(avgGraphite);     
  }

  // --- Retour ---
  for(int i=numSteps; i>=0; i--){
    int angle = round(i*angleStep);
    myservo.write(angle);
    delay(stepDelay);

    float sumFlex = 0;
    float sumGraphite = 0;

    for(int m=0; m<numMeasures; m++){
      int adcFlex = analogRead(FLEX_PIN);
      float Rflex = R_SHUNT * (1023.0/float(adcFlex) - 1.0);
      sumFlex += Rflex;
      int adcGraphite = analogRead(GRAPHITE_PIN);
      float Vgraphite = adcGraphite * (5.0 / 1024.0);
      float Rgraphite = (1+(R3/R_POTARD))*R1*(VCC/Vgraphite)-R1-R5 ;
      sumGraphite += Rgraphite;
    }

    float avgFlex = sumFlex/float(numMeasures);
    float avgGraphite = sumGraphite/float(numMeasures);

    String Data = String(avgFlex) + ";" + String(avgGraphite) ;
    mySerial.println("D: " + Data);
  }
  Serial.println("END"); // fin cycle
}

//-------------------------------------------------//
//                                                 //
//                      SETUP                      //
//                                                 //
//-------------------------------------------------//

void setup() {
  Serial.begin(9600);

  // Bluetooth
  mySerial.begin(speed_serial); // initialisation de la connexion série (avec le module bluetooth)
  pinMode (rxPin,INPUT);
  pinMode (txPin,OUTPUT);

  // Servo
  myservo.attach(SERVO_PIN);
  myservo.write(0);

  // Potentiomètre
  pinMode (ssMCPin, OUTPUT); //select pin output
  digitalWrite(ssMCPin, HIGH); //SPI chip disabled
  SPI.begin(); 
}

//-------------------------------------------------//
//                                                 //
//                       MAIN                      //
//                                                 //
//-------------------------------------------------//
int resultat; // valeur de la position du potentiomètre pour mettre la valeur de la tension à 2,5V

void loop() {
  // Savoir si une donnée est disponible
  if (mySerial.available() > 0) {

    //Attendre un peu (pour éviter les bugs)
    delay(10);

    int len = mySerial.readBytesUntil('\n', serialRX, sizeof(serialRX) - 1);
    serialRX[len] = '\0';  // fin de chaîne obligatoire
 
    // Afficher ce qu'on a reçu
    //Serial.print("Recu : ");
    //Serial.println(serialRX);
 
    // Case pour faire des actions selon la valeur reçue
    switch (serialRX[0]) {
      case '1':   // Si nombre 1 reçu : calibration
        Serial.println("Calibration lancée");
        resultat = Calibration();
        char buffer[20];
        sprintf(buffer, "C:%d", resultat);
        Serial.println(buffer);
        mySerial.println(buffer);
        break;

      case '2': // Si nombre 2 reçu : lancer la mesure
        Serial.println("Mesure en cours");
        // --- Lancement cycle ---
        if(readyToStart){
          runCycle();
        }
        break;

      case 'A':
        angleMax = atoi(serialRX + 1);
        Serial.print("Nouvelle valeur d'angle : "); Serial.println(angleMax);
        break;

      case 'M':
        numMeasures = atoi(serialRX + 1);
        Serial.print("Nouvelle valeur d'mesure : "); Serial.println(numMeasures);
        break;

      case 'P':
        numSteps = atoi(serialRX + 1);
        Serial.print("Nouvelle valeur d'pas : "); Serial.println(numSteps);
        break;
    }
  }
  delay(5);
}

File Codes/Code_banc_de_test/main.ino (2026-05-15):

#include <Wire.h>
#include <Adafruit_SSD1306.h>
#include <Adafruit_GFX.h>
#include <Servo.h>

// --- OLED 128x64 ---
#define SCREEN_WIDTH 128
#define SCREEN_HEIGHT 64
#define OLED_RESET    -1
Adafruit_SSD1306 display(SCREEN_WIDTH, SCREEN_HEIGHT, &Wire, OLED_RESET);

// --- Encodeur ---
const int ENC_CLK = 2;
const int ENC_DT  = 4;
const int ENC_SW  = 5;

// --- Servo ---
Servo myservo;
const int SERVO_PIN = 6;

// --- Capteurs ---
const int FLEX_PIN      = A1;
const int GRAPHITE_PIN  = A0;
const float R_SHUNT     = 10000.0; // Flex 10kΩ
const float GAIN        = 1.0;     // Graphite amplifié

// --- Encodeur variables ---
volatile int encoderPos = 0;
int lastCLK = LOW;
bool lastButtonState = HIGH;
unsigned long lastDebounceTime = 0;
const unsigned long debounceDelay = 50;

// --- Paramètres ---
int angleMax = 90;
int numSteps = 90;
int numMeasures = 1;
int parameterIndex = 0;
bool readyToStart = false;

// --- Menu capteur ---
enum SensorMode { FLEX_ONLY, GRAPHITE_ONLY, BOTH };
SensorMode sensorMode = FLEX_ONLY;

void setup() {
  Serial.begin(115200);

  // OLED
  if(!display.begin(SSD1306_SWITCHCAPVCC, 0x3C)){ while(1); }
  display.clearDisplay();
  display.setTextSize(1);
  display.setTextColor(SSD1306_WHITE);

  // Encodeur
  pinMode(ENC_CLK, INPUT);
  pinMode(ENC_DT, INPUT);
  pinMode(ENC_SW, INPUT_PULLUP);
  lastCLK = digitalRead(ENC_CLK);
  attachInterrupt(digitalPinToInterrupt(ENC_CLK), handleEncoder, CHANGE);

  // Servo
  myservo.attach(SERVO_PIN);
  myservo.write(0);

  displayParameters();
}

void loop() {
  // --- Bouton ---
  bool reading = digitalRead(ENC_SW);
  if(lastButtonState == HIGH && reading == LOW){
    if(millis() - lastDebounceTime > debounceDelay){
      lastDebounceTime = millis();
      parameterIndex++;
      if(parameterIndex > 3){
        readyToStart = true;
        parameterIndex = 0;
      }
      displayParameters();
    }
  }
  lastButtonState = reading;

  // --- Appliquer rotation encodeur ---
  noInterrupts();
  int pos = encoderPos;
  encoderPos = 0;
  interrupts();

  if(pos != 0){
    switch(parameterIndex){
      case 0: // angleMax
        angleMax += pos;
        if(angleMax < 1) angleMax = 1;
        if(angleMax > 180) angleMax = 180;
        numSteps = angleMax;
        break;
      case 1: // nombre de pas
        numSteps += pos;
        if(numSteps < 1) numSteps = 1;
        if(numSteps > 500) numSteps = 500;
        break;
      case 2: // numMeasures
        numMeasures += pos;
        if(numMeasures < 1) numMeasures = 1;
        if(numMeasures > 20) numMeasures = 20;
        break;
      case 3: // choix capteur
        int mode = int(sensorMode) + pos;
        if(mode < 0) mode = 2;
        if(mode > 2) mode = 0;
        sensorMode = SensorMode(mode);
        break;
    }
    displayParameters();
  }

  // --- Lancement cycle ---
  if(readyToStart){
    displayMessage("Cycle démarré...");
    runCycle();
    displayMessage("Cycle terminé");
    readyToStart = false;
    parameterIndex = 0;
    displayParameters();
  }

  delay(5);
}

// --- Interrupt encodeur ---
void handleEncoder(){
  int clkState = digitalRead(ENC_CLK);
  int dtState  = digitalRead(ENC_DT);

  if(clkState != lastCLK){
    if(dtState != clkState) encoderPos++;
    else encoderPos--;
  }
  lastCLK = clkState;
}

// --- Affichage OLED ---
void displayParameters(){
  display.clearDisplay();
  display.setCursor(0,0);
  display.println(F("Réglage parametres:"));
  
  display.print(F("Angle max: ")); display.println(angleMax);
  if(parameterIndex==0) display.println(F("<--"));
  
  display.print(F("Nombre de pas: ")); display.println(numSteps);
  if(parameterIndex==1) display.println(F("<--"));
  
  display.print(F("Mesures/angle: ")); display.println(numMeasures);
  if(parameterIndex==2) display.println(F("<--"));

  display.print(F("Capteur: "));
  switch(sensorMode){
    case FLEX_ONLY: display.println(F("Flex")); break;
    case GRAPHITE_ONLY: display.println(F("Graphite")); break;
    case BOTH: display.println(F("Les deux")); break;
  }
  if(parameterIndex==3) display.println(F("<--"));

  if(readyToStart){
    display.println();
    display.println(F("PRÊT A LANCER"));
  }
  display.display();
}

void displayMessage(String msg){
  display.clearDisplay();
  display.setCursor(0,0);
  display.println(msg);
  display.display();
}

// --- Cycle servo + mesure ---
void runCycle(){
  Serial.println("START"); // signal pour Python

  float angleStep = float(angleMax)/float(numSteps);
  int stepDelay = 25; // ms

  for(int i=0; i<=numSteps; i++){
    int angle = round(i*angleStep);
    myservo.write(angle);
    delay(stepDelay);

    float sumFlex = 0;
    float sumGraphite = 0;

    for(int m=0; m<numMeasures; m++){
      if(sensorMode == FLEX_ONLY || sensorMode == BOTH){
        int adcFlex = analogRead(FLEX_PIN);
        float Rflex = R_SHUNT * (1023.0/float(adcFlex) - 1.0);
        sumFlex += Rflex;
      }
      if(sensorMode == GRAPHITE_ONLY || sensorMode == BOTH){
        int adcGraphite = analogRead(GRAPHITE_PIN);
        float Rgraphite = float(adcGraphite) * GAIN;
        sumGraphite += Rgraphite;
      }
    }

    float avgFlex = (sensorMode == FLEX_ONLY || sensorMode == BOTH) ? sumFlex/float(numMeasures) : 0;
    float avgGraphite = (sensorMode == GRAPHITE_ONLY || sensorMode == BOTH) ? sumGraphite/float(numMeasures) : 0;

    Serial.print("A"); Serial.print(angle);
    if(sensorMode == FLEX_ONLY) Serial.print("\t"), Serial.println(avgFlex);
    else if(sensorMode == GRAPHITE_ONLY) Serial.print("\t"), Serial.println(avgGraphite);
    else Serial.print("\t"), Serial.print(avgFlex), Serial.print("\t"), Serial.println(avgGraphite);
  }

  // --- Retour ---
  for(int i=numSteps; i>=0; i--){
    int angle = round(i*angleStep);
    myservo.write(angle);
    delay(stepDelay);

    float sumFlex = 0;
    float sumGraphite = 0;

    for(int m=0; m<numMeasures; m++){
      if(sensorMode == FLEX_ONLY || sensorMode == BOTH){
        int adcFlex = analogRead(FLEX_PIN);
        float Rflex = R_SHUNT * (1023.0/float(adcFlex) - 1.0);
        sumFlex += Rflex;
      }
      if(sensorMode == GRAPHITE_ONLY || sensorMode == BOTH){
        int adcGraphite = analogRead(GRAPHITE_PIN);
        float Rgraphite = float(adcGraphite) * GAIN;
        sumGraphite += Rgraphite;
      }
    }

    float avgFlex = (sensorMode == FLEX_ONLY || sensorMode == BOTH) ? sumFlex/float(numMeasures) : 0;
    float avgGraphite = (sensorMode == GRAPHITE_ONLY || sensorMode == BOTH) ? sumGraphite/float(numMeasures) : 0;

    Serial.print("R"); Serial.print(angle);
    if(sensorMode == FLEX_ONLY) Serial.print("\t"), Serial.println(avgFlex);
    else if(sensorMode == GRAPHITE_ONLY) Serial.print("\t"), Serial.println(avgGraphite);
    else Serial.print("\t"), Serial.print(avgFlex), Serial.print("\t"), Serial.println(avgGraphite);
  }

  Serial.println("END"); // fin cycle
}

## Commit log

2026-05-15 Rename adaptateur boite-Body.step to Banc_de_test/adaptateur boite-Body.step
    [adaptateur boite-Body.step]
2026-05-17 Revise README for clarity on PCB and sensor testing
    Updated the README to clarify the design process and results of the PCB and sensor tests, including changes to the Arduino code and Android application details.

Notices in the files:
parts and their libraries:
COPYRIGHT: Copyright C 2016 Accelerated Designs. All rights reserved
